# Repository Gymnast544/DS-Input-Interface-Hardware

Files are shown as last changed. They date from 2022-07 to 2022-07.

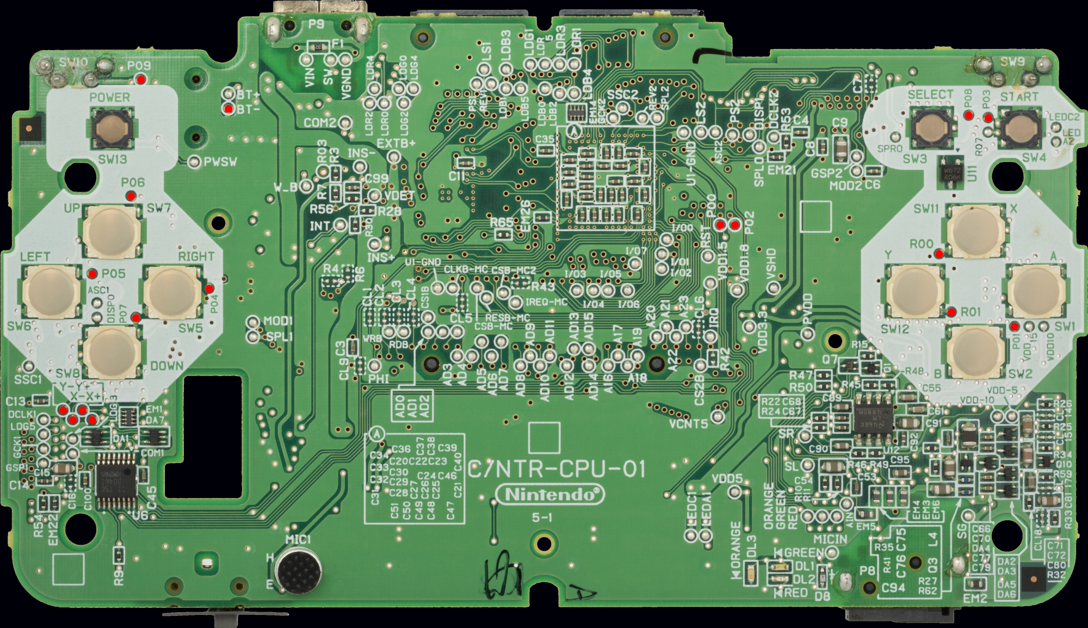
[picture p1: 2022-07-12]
mobopinout.png

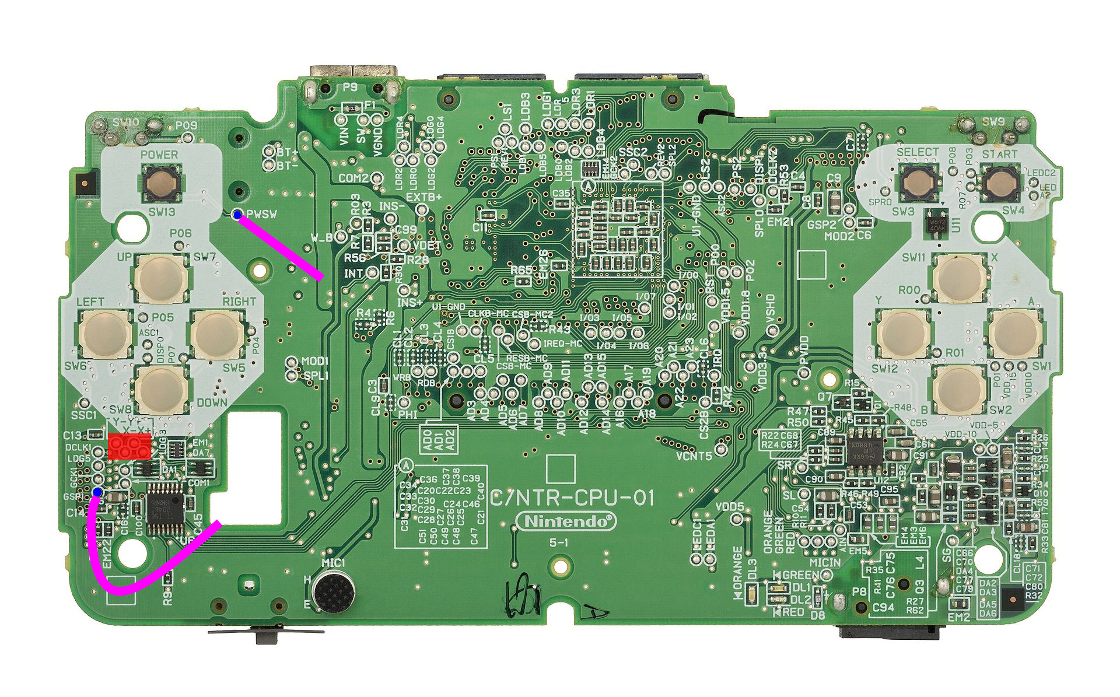
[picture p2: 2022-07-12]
tasmodehardwarediagram1.png

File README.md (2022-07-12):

# DS-Input-Interface-Hardware

These are the hardware files I used to make the DS Input Interface. The files are a bit messy but the Flex PCB is in my opinion a pretty good way to connect a microcontroller to all the DS inputs and mount it nicely on the back of the DS. There's also some hardware notes and drawings about touchscreen control.

I did all of the drawing for the PCB in Inkscape, as it was easy to have a correctly scaled image of the DS motherboard and measure the positions of the pads from that image. I believe I used svg2shenzhen (https://github.com/badgeek/svg2shenzhen) to convert from the inkscape drawing to KiCad. I then used KiCad for exporting gerber files. There are gerbers already exported in one of the folders, if you want to simply order another batch of the flex cables. Tip for ordering: order in bulk, as when ordering <5 the prices are enormous - it cost me just under 1/2 as much to order 3 of my test PCBs as it did to order 15. I ordered from PCBway, I think I went with 2 layers of copper, though the traces are routed such that a single layer flex PCB should work fine.

I've included the 3d printer files for the covers. The Pro Micro board is what I used in the kits I sold, as they're very cheap and easy to use and install. For my DS with touchscreen capability, I used a Teensy 4.0, which is far more powerful and makes touchscreen emulation a lot easier to program, as emulating the SPI interface using the microcontroller's builtin SPI mode wasn't something I was successful at.

There are more details on the Notion page I wrote: https://www.notion.so/gymnast544mods/DS-Input-Interface-784026d380254c439d2e0b6848e682f9
For software setup of a Pro Micro board (easiest install) look here: https://github.com/Gymnast544/DS-Input-Interface-Software/tree/master/Pro%20Micro%20Code/ds_tas_master 

I sold them on my Tindie (https://www.tindie.com/products/gymnast544mods/ds-input-interface/), not sure if I'll ever do that again.

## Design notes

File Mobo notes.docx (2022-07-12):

Mobo notes:

- Board thickness – 1mm
- Bottom screen connector thickness (including board) – 3mm
- Cart slot height – 7mm (not including board)

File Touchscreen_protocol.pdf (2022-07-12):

Touchscreen protocol | 1

# Touchscreen protocol

Command to the touchscreen driver

Power Down mode is pretty irrelevant for this

SER/DFR also seems irrelevant as the x pos measure and y pos measure commands are the same for A bits

Touchscreen driver running on 3.3 Volts - teensy should control it just fine

MOSI - Rising

MISO - Falling

First bit is MOSI saying 132:

MOSI bits

1. HIGH - Setting
2. LOW - A2
3. LOW - A1
4. LOW - A0
5. LOW - Mode (12 bit conversion, not 8 bit)
6. HIGH - SER/DFR (It's in single ended mode)
7. LOW - PD1
8. LOW - PD0

If it's pressed then it alternates between 209 and 0 4 times (MOSI)

A bits saying it's measuring the X pos

Touchscreen protocol | 2

209:

1. Start (always high) - HIGH
2. A2 - HIGH
3. A1 - LOW
4. A0 - HIGH
5. Mode (12 bit vs 8 bit) - LOW - 12 bits
6. SER - DFR - LOW
7. PD1 - LOW
8. PD0 - HIGH

11010001 - X pos measure

10010001 - Y pos measure

1000 01000

1011 0101 - z pos

1100 0101 - z pos

Reference mode - Single ended

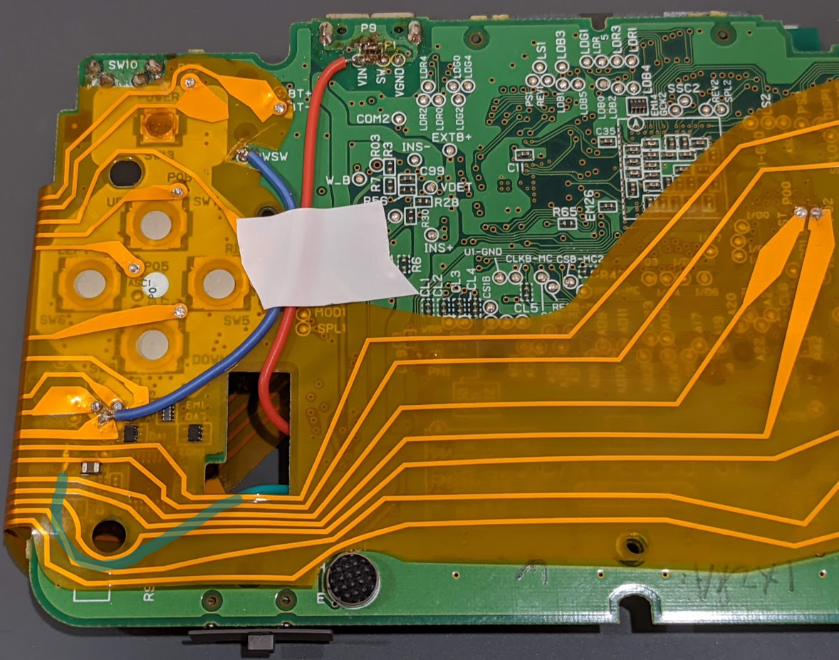
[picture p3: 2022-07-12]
tas mode hardware 2.png

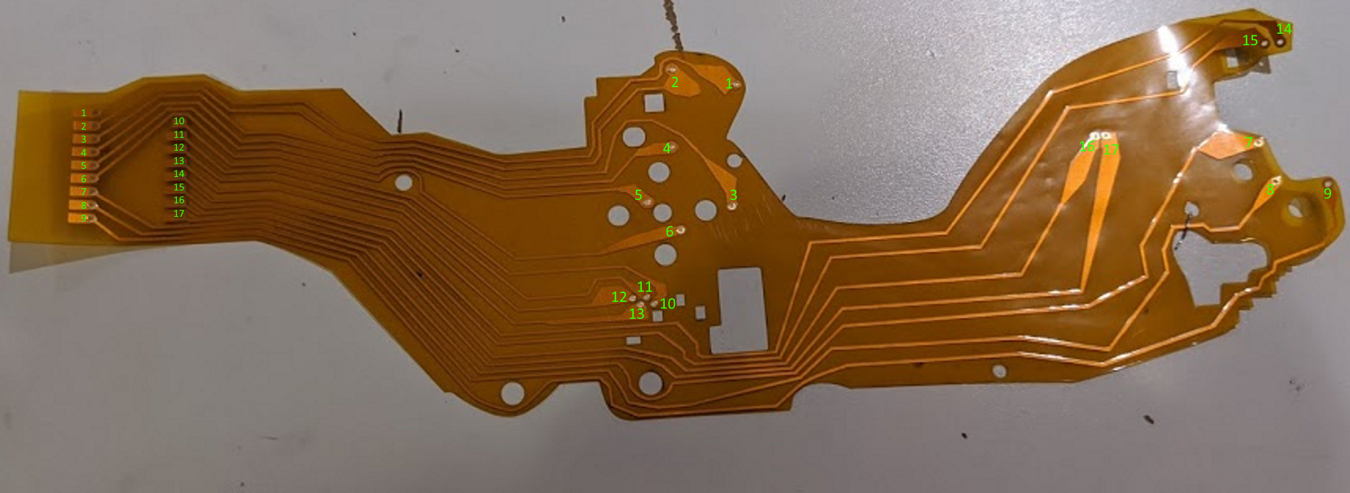
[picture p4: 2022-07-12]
trace connections.png

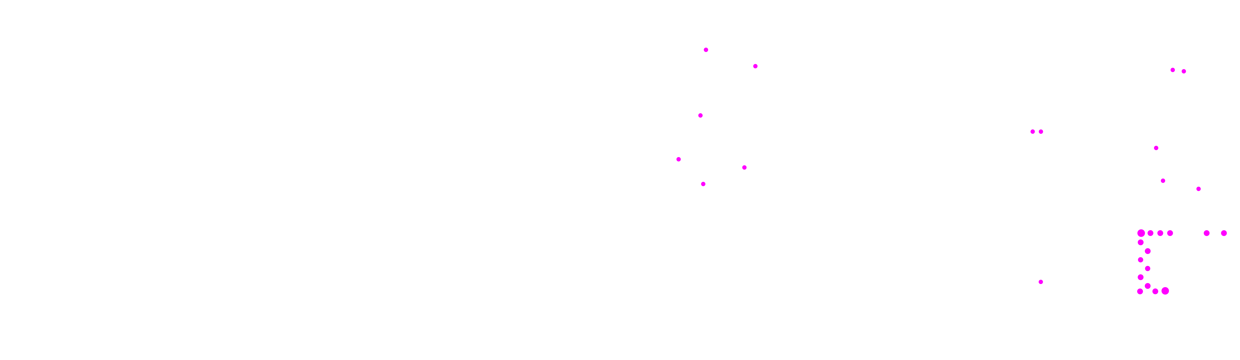
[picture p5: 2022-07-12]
DS Input Capture KiCAD V1.2/.svg2shenzhen-cache/images/B.Mask_g1286.png

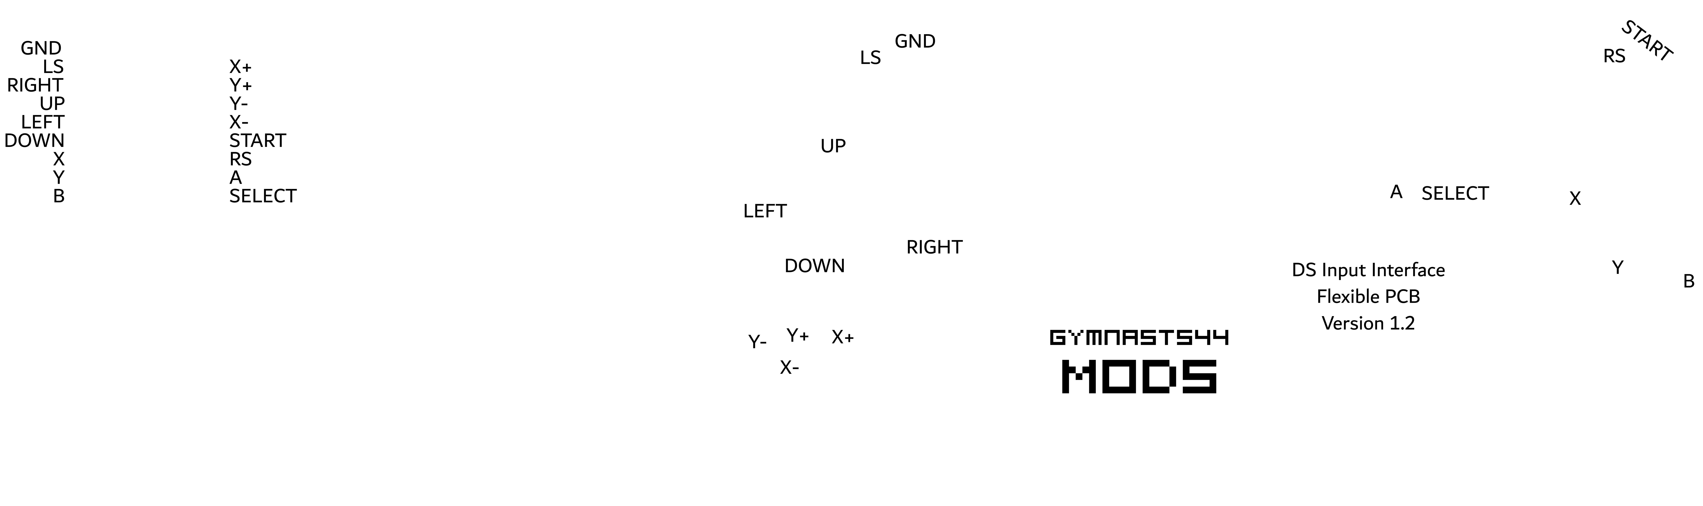
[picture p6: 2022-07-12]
DS Input Capture KiCAD V1.2/.svg2shenzhen-cache/images/F.Silk_layer3.png

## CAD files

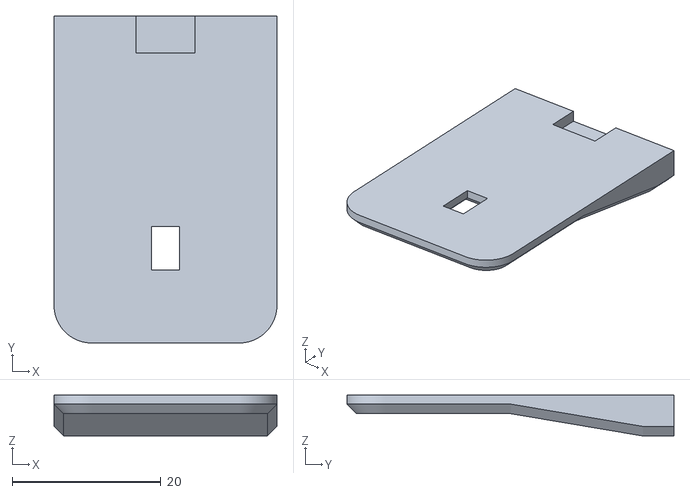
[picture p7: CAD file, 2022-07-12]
Teensy 4 DS back cover.stl
30.0 x 44.0 x 5.50

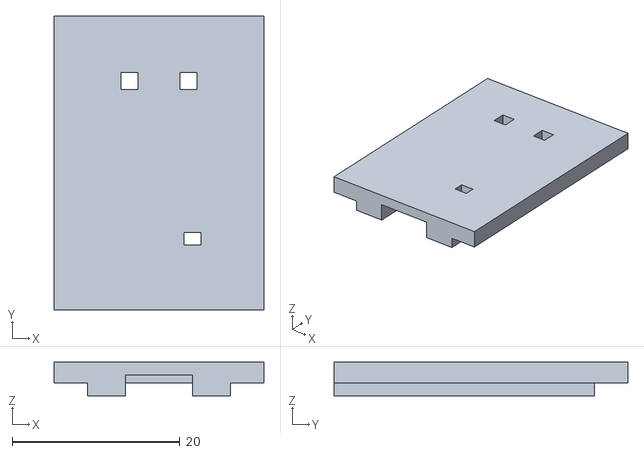
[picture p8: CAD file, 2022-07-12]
Pro Micro cover.stl
25.0 x 35.0 x 4.00

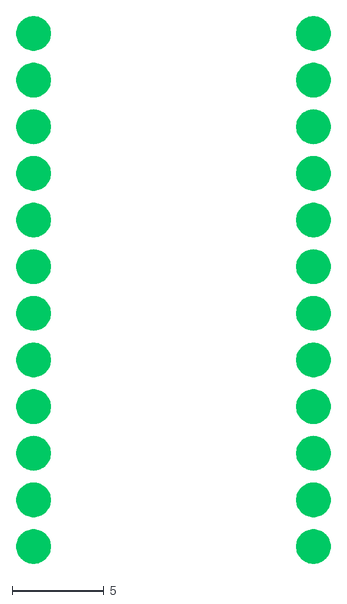
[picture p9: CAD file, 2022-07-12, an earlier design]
old-files/SparkFun_Pro_Micro.dxf
17.1 x 29.8

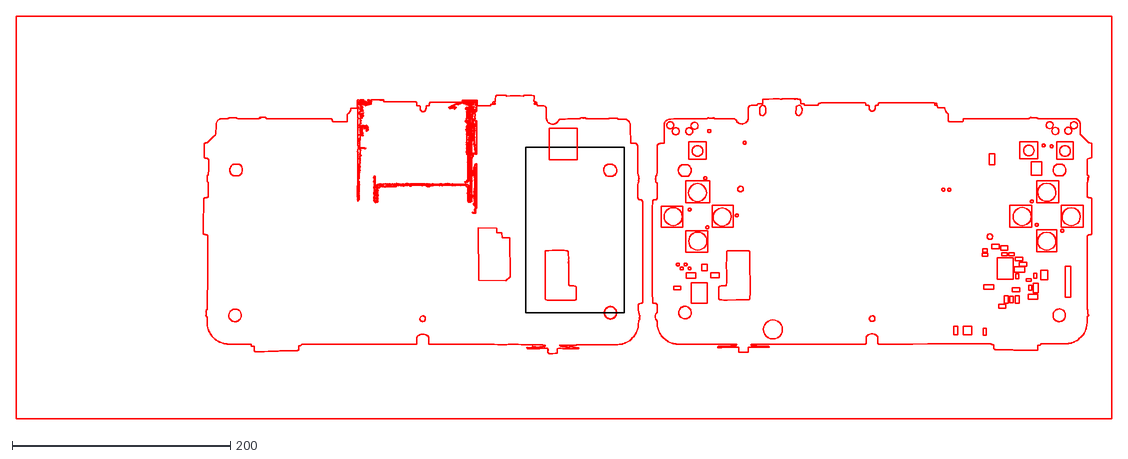
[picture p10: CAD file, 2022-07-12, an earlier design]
old-files/Aligned mobo.dxf
1002.9 x 368.6

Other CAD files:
Part Studio 1 - Teensy 4 DS back cover.step
Pro Micro cover.ipt
old-files/promicrodrawing.idw

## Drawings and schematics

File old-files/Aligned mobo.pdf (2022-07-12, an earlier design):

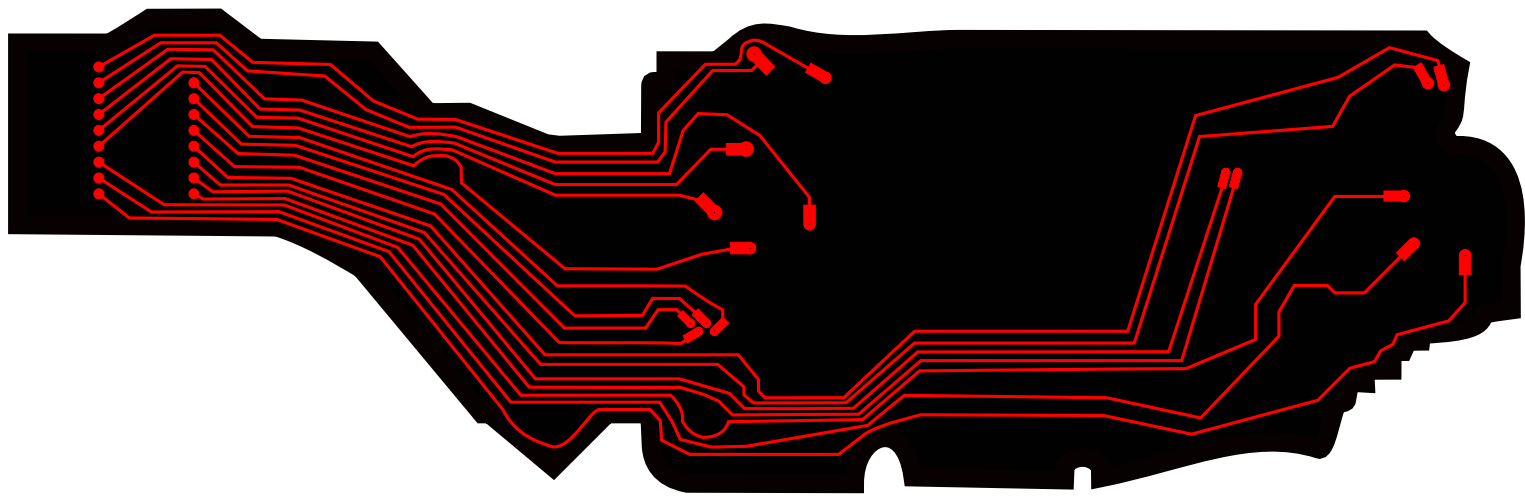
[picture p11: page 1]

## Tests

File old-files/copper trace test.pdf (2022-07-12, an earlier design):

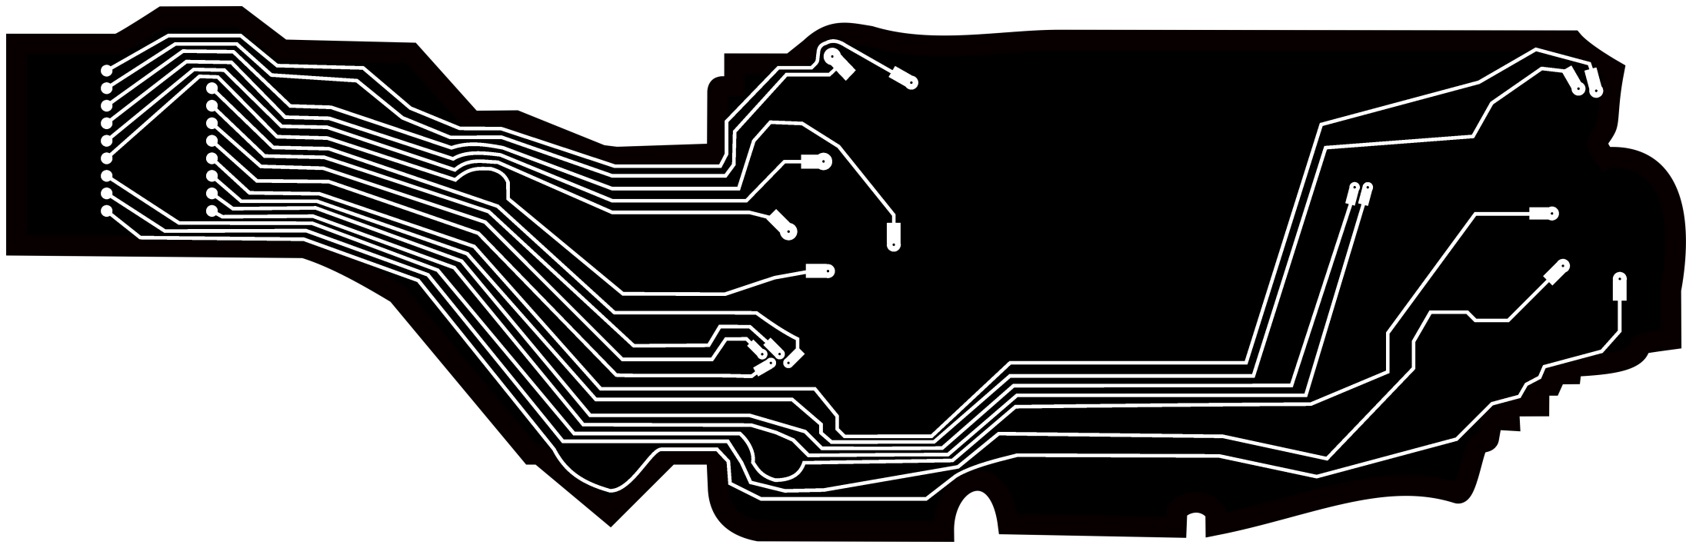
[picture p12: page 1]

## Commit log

2022-07-12 Uploaded files.
    [Aligned mobo-B_Cu.gbr, Aligned mobo-B_Mask.gbr, Aligned mobo-Edge_Cuts.gbr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]
2022-07-12 Updated stuff
    [Part Studio 1 - Teensy 4 DS back cover.step, Pro Micro cover.ipt, Pro Micro cover.stl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]
